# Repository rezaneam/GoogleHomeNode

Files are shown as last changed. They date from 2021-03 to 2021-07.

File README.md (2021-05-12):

# Smart IoT Sensor - Lite Version of [sAmbiente](https://github.com/rezaneam/sAmbiente)

This project introduces proof of concept for a Smart Home Device/Sensor/Monitoring with a different approach.
In this project, Bosch & TI environment sensors (BMP280, BME280, BME680, HDC1080) were utilized to monitor the temperature, humidity, pressure, and air quality.

<p align="center">
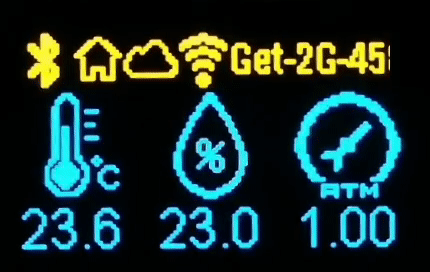
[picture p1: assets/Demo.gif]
  
</p>

## What is innovative in this project

- The configuration process of the Smart IoT Sensor is straightforward and you can update it at anytime.
- The Sensor pushes real-time readings via BluetoothLE to multiple connected devices.
- Against many available solutions, you don't need to open a port in your router/modem/firewall. That's really cumbersome and may be secuirty issues.
- You don't need to deal with DNS and static IP address. that's a real pain.
- You don't need to register on expensive and complicated services (Azure IoT Hub service has a free plan).
- You can customize the whole project with a little effort.

## Components

This project includes the following components

- ESP32 (Smart IoT Sensor):

It's the main IoT device which basically is an ESP32 module connected to an environment sensor. The module needs to connect to the Internet via WiFi and connect to Azure services. This project is written in `Platform IO` so it should take care of everything (external libraries) if you use `Platform IO`.
You should be able to connect to the device and configure it via BluetoothLE and at any time, you can update the sensor configuration without any need to reset it.
WiFi name, Password, Azure Connection string, Google Home, device location (for example, kitchen, living room) are configuration values needed to be set. Hopefully, UWP and Xamarin applications will help you to do it with any challenges.

- UWP Application:

This application is just for configuring the Google Home node. It's basically a `Windows 10` application and will show up in `Windows store` soon :)
By the way, you can run on Desktop, Windows Mobile, and `Windows IoT Core` (`Raspberry Pi`).

- ~~Xamarin Application~~: (not ready yet)

This project is an extended version of UWP Application for `Android` and `iOS` platform. Not ready yet.

- Azure:

This is an Azure Function app if you want to use your own `Azure service`. contact me if you can't follow me.

## How set it up

- Google Home Node

First thing first, You need to build the Google Home Node device and program it.
I would recommend you first test it with a very basic ESP32 evaluation board and a BMP280/BME280 breakout board. This setup would cost you less than 5 USD. Of course, having a `SSD1306` is a plus.
Wire the sensor as is shown in the following figure and flash the board via Platform IO in `Visual Studio Code`.

<p align="center">
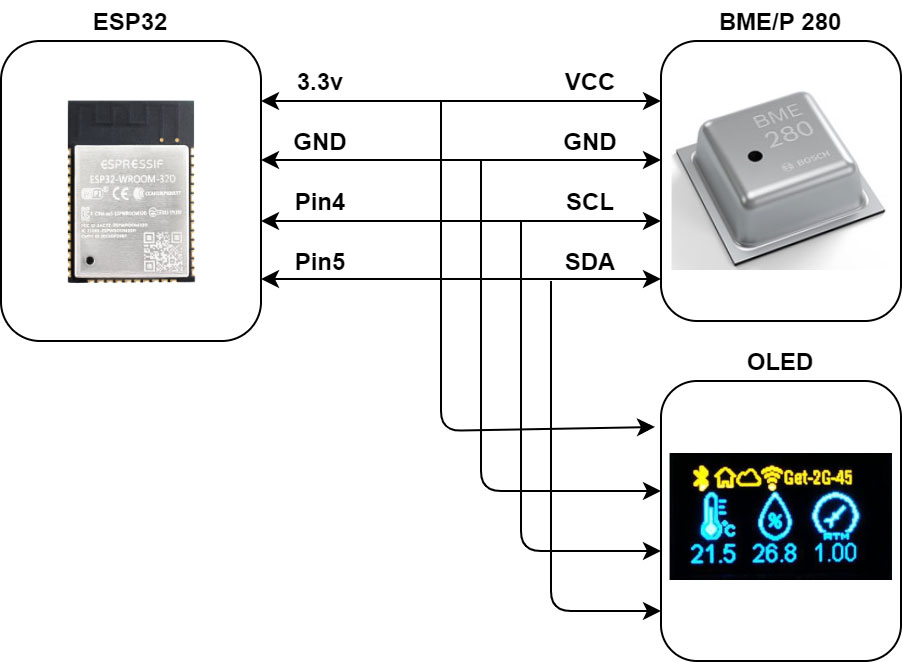
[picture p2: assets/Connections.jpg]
  
</p>

You can always reconfigure the connection by changing the pin numbers in [config.h](ESP32/src/config.h).

You can also use the PCB design to make your custom compact module with more functionality and battery support.
Find the attached 3.5x3.5 cm [PCB design](/KiCad-Design/KiCad-Design.kicad_pcb).

PCB layout

<span align="center">
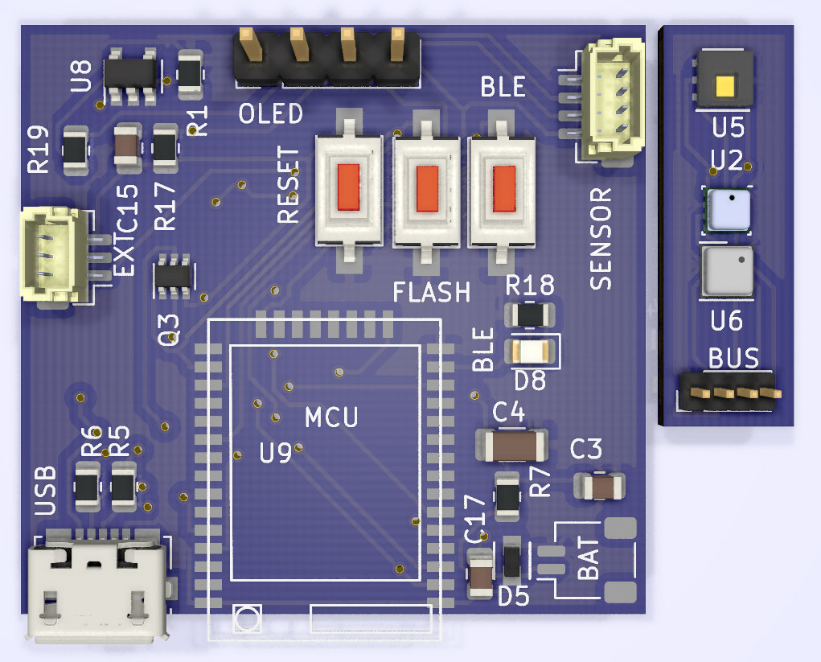
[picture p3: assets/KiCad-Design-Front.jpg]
  
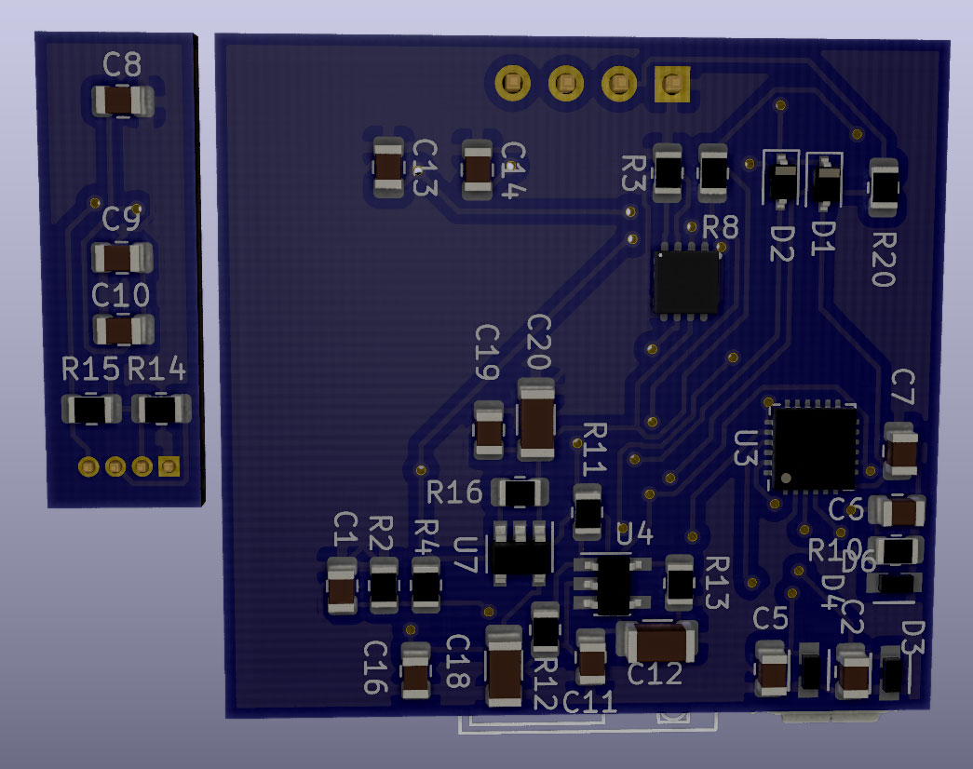
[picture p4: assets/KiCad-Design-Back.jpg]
  
</span>

- Azure IoT Hub

After creating the `Azure` account the first step is to make a new `IoT Hub` service in your Azure account. To do so just type in IoT Hub and create a new account (you pick F1 which is entirely free). Then Navigate to the IoT Hub service you created and make an IoT Device.
Click on the IoT Device that you have just created and copy the connection string. You need to set this connection string in your Google Home node.
To test if this part is working properly just send a direct method with the following payload and check the logs in your serial port.

{
"Action": "Google Home",
"UserID": "`YourUserID`",
"Language": "en",
"Key": "temperature"
}

So, now you are done with this part.

- Azure Function

In the same way make an `Azure Function App` service in your Azure account. Pick .Net 3.1 version and Free version in the Function App.
Open Azure project repository and update the _IoTHubName_, _IoTDeviceName_, and _IoTSharedAccessKey_ values and then Publish the function in your Azure account.
To test this step just copy the Function App **URL** and use postman to send a post message with the following body.

{
"Action": "Google Home",
"UserID": "`YourUserID`",
"Language": "en",
"Key": "temperature"
}

- IFTTT

You need to make an IFTTT account (it's free) and make a scenario called.
Try to create an applet in IFTTT, add `Google Assistant` as a trigger source. Remember to pick _say a phrase with a text ingredient_
Type in your preferred keywords followed by $ sign and provide a response for that.
Then pick `Webhooks` (web request) as the service. So copy and paste the `Azure Function App` URL from the previous step in URL field. You pick either Get or Post request and for the content type choose JSON. paste the following structure there.

{
"Action": "Google Home",
"Language": "en",
"UserID": "`YourUserID`",
"Key": "TextField"
}

## How it is working

The following figure shows the overal concept of the project.

<p align="center">
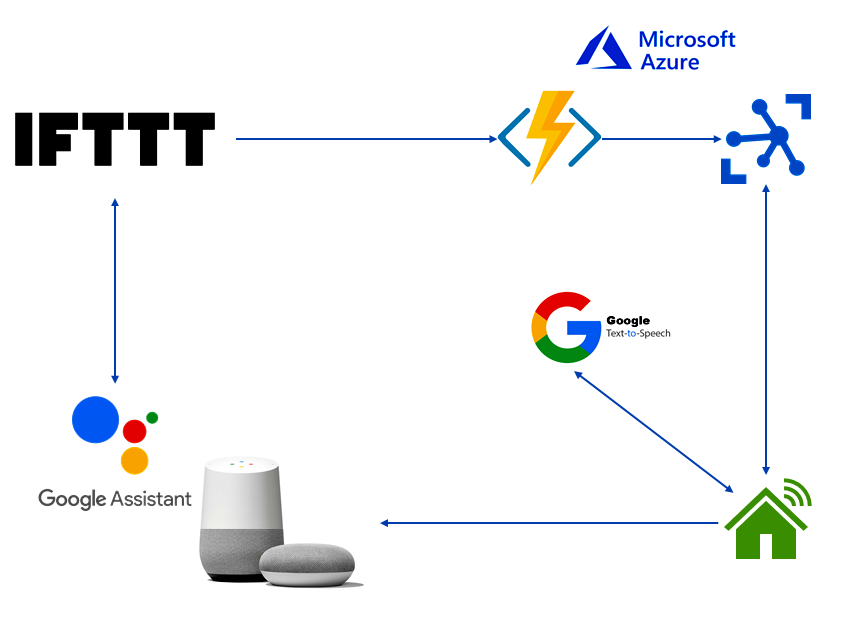
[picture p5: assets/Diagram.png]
  
</p>

The Google Home Node (main ESP32 module) starts to connect to Azure IoT service (as set in the configuration) and tries to find the local `Google Home speaker` (namely Google Home, Google Home Mini, or any Google Home enable speaker). It also drives the OLED and the sensor.
The Google Home Node is always in listening mode (at least for now) and doesn't send any information to `Azure IoT Hub`.

When you ask `Google Assistant` to give you the home temperature (or specific location/node), Google Assistant (not Google Home speaker) triggers an action in the IFTTT (which you have previously defined).

`IFTTT` triggers a webhook (better to an HTTP request) which actually an Azure Function with some inputs (username, keywords).
The received information from Azure Function is sent to the Azure IoT and eventually received by the Google Home Node.

Google Home Node would take action if the received information matches (username, location, etc.). So Google Home Node asks the Google Home speaker (already linked) to say the temperature, humidity, ... values.
I used [esp8266 Google TTS](https://github.com/horihiro/esp8266-google-tts) to generate an audio file and [esp8266 Google Home Notifier](https://github.com/horihiro/esp8266-google-home-notifier) to push the message/notification to the Google Home Speaker.

## Platform/IDE(s)

- [Platform IO](https://platformio.org/)
- [Arduino](https://www.arduino.cc/)
- [Espressif ESP-32](https://www.espressif.com/en/products/socs/esp32)

## Supported Sensors

- [Bosch BMP280](https://www.bosch-sensortec.com/products/environmental-sensors/pressure-sensors/bmp280/)
- [Bosch BME280](https://www.bosch-sensortec.com/products/environmental-sensors/humidity-sensors-bme280/)
- [Bosch BME680](https://www.bosch-sensortec.com/products/environmental-sensors/gas-sensors/bme680/). You need a [permission](https://www.bosch-sensortec.com/media/boschsensortec/downloads/bsec/2017-07-17_clickthrough_license_terms_environmentalib_sw_clean.pdf) to use [Bosch Sensortec Environmental Cluster(BSEC) Library](https://github.com/BoschSensortec/BSEC-Arduino-library). Please visit this [page](https://www.bosch-sensortec.com/software-tools/software/bsec/)
- [Texas Instrument HDC1080](https://www.ti.com/lit/ds/symlink/hdc1080.pdf)

## Dependent Libraries

- [Azure IoT Arduino](https://github.com/Azure/azure-iot-arduino)
- [Azure IoT Protocol HTTP](https://github.com/Azure/azure-iot-arduino-protocol-http)
- [Azure IoT Protocol MQTT](https://github.com/Azure/azure-iot-arduino-protocol-mqtt)
- [Azure IoT Utility](https://github.com/Azure/azure-iot-arduino-utility)
- [NimBLE Arduino](https://github.com/h2zero/NimBLE-Arduino) - Lite version of the BluetoothLE to save some RAM
- [esp8266 Google Home Notifier](https://github.com/horihiro/esp8266-google-home-notifier) - Customized version to support different languages.
- [esp8266 Google TTS](https://github.com/horihiro/esp8266-google-tts)
- [Adafruit BME280 Library](https://github.com/adafruit/Adafruit_BME280_Library) - Locally/Modified in the project
- [ThingPulse SSD1306](https://github.com/ThingPulse/esp8266-oled-ssd1306) - Extensively modified and locally imported.
- [BSEC Arduino Library](https://github.com/BoschSensortec/BSEC-Arduino-library) - Please visit this [page](https://www.bosch-sensortec.com/software-tools/software/bsec/)
- TO DO: [Texas Instrument HDC1080](https://www.ti.com/lit/ds/symlink/hdc1080.pdf)

## Future Improvment

- Improving the UWP Application layout and code logic
- Deploy UWP App in the Windows Store
- Support for Android & iOS platforms (Xamarin Forms)
- Better desgin for multi-language support (EN, DE, FR)
- Find a way to integrate with Google Assistant
- Connect to [HASS](https://www.home-assistant.io/)

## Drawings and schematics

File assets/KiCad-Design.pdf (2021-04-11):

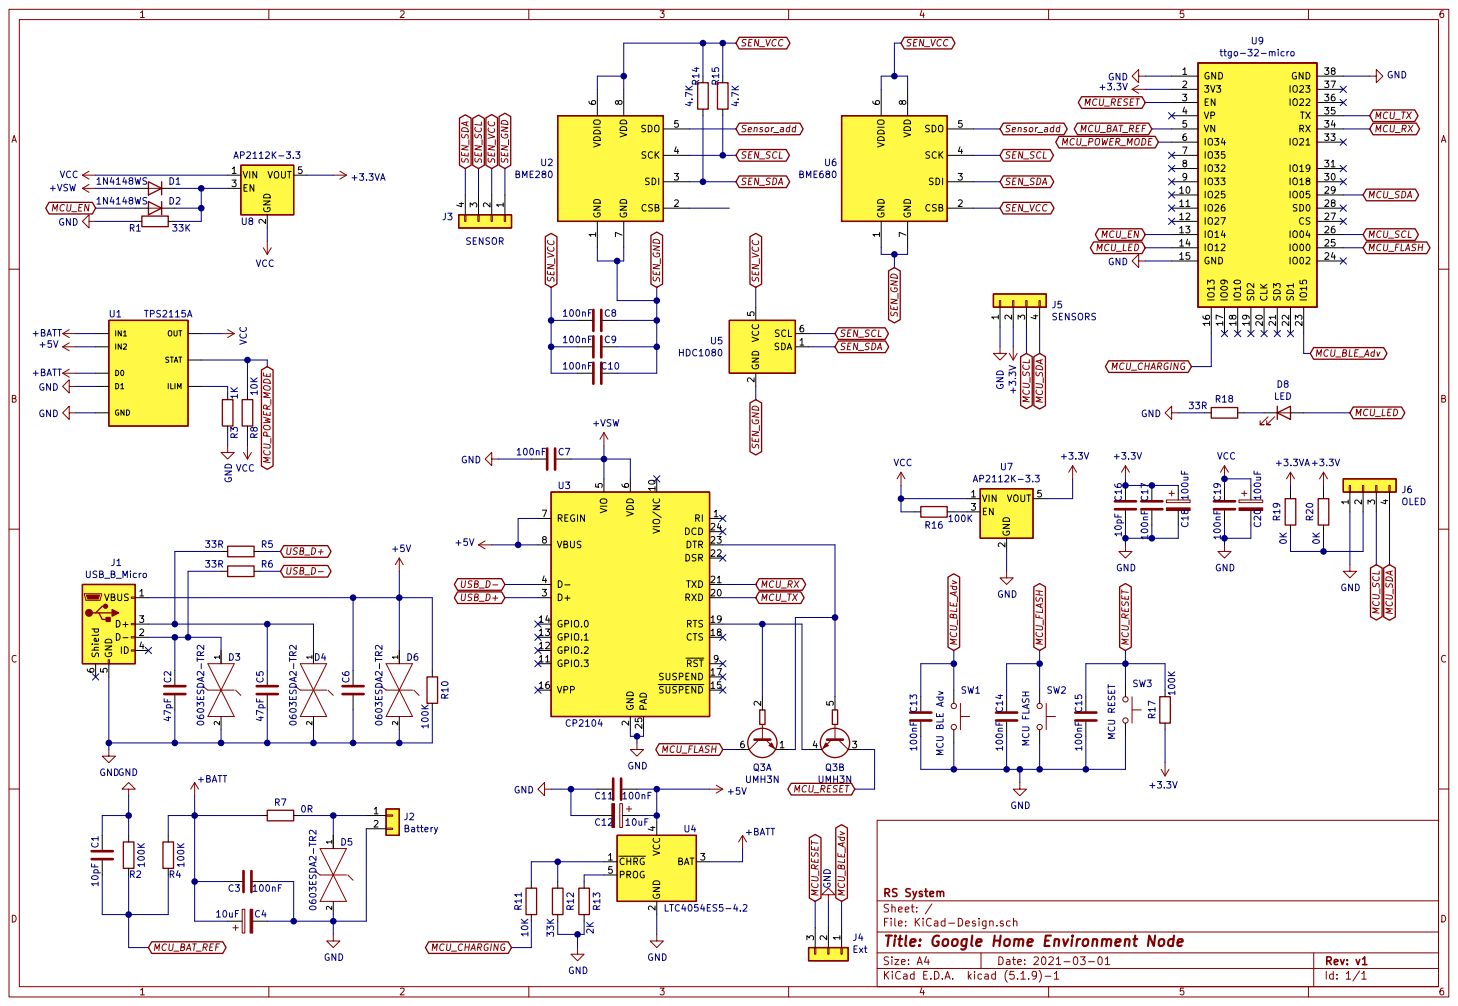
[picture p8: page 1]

1 CSB 2 SDI 3 SCK 4 SDO 5 VDDIO

6 REGIN 7 VBUS 8 RST 9 U3CP2104 GND

2 RXD 20 TXD 21 DSR 22 DTR 23 DCD 24 PAD 25 D+ 3 D- 4 VIO

Id: 1/1 Title: Google Home Environment Node

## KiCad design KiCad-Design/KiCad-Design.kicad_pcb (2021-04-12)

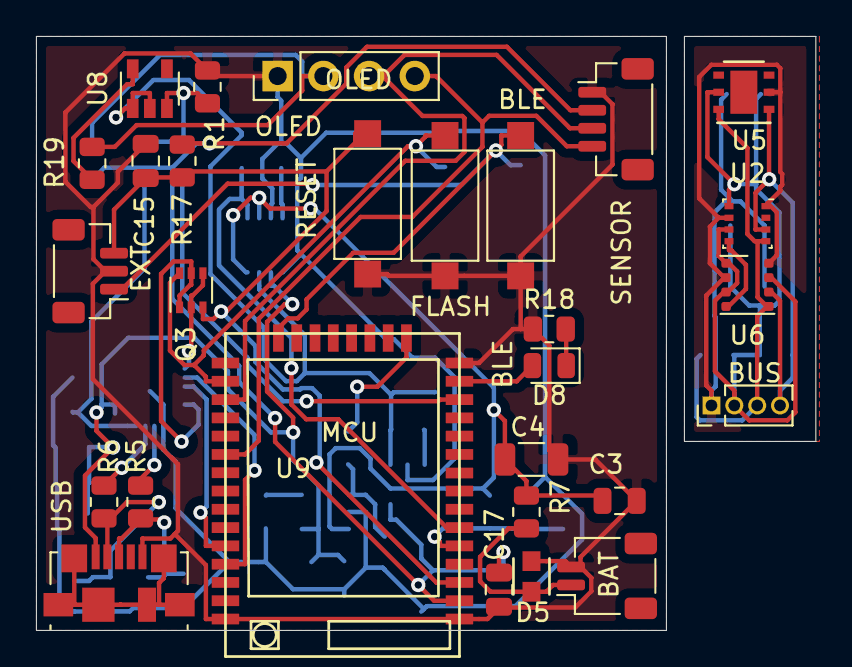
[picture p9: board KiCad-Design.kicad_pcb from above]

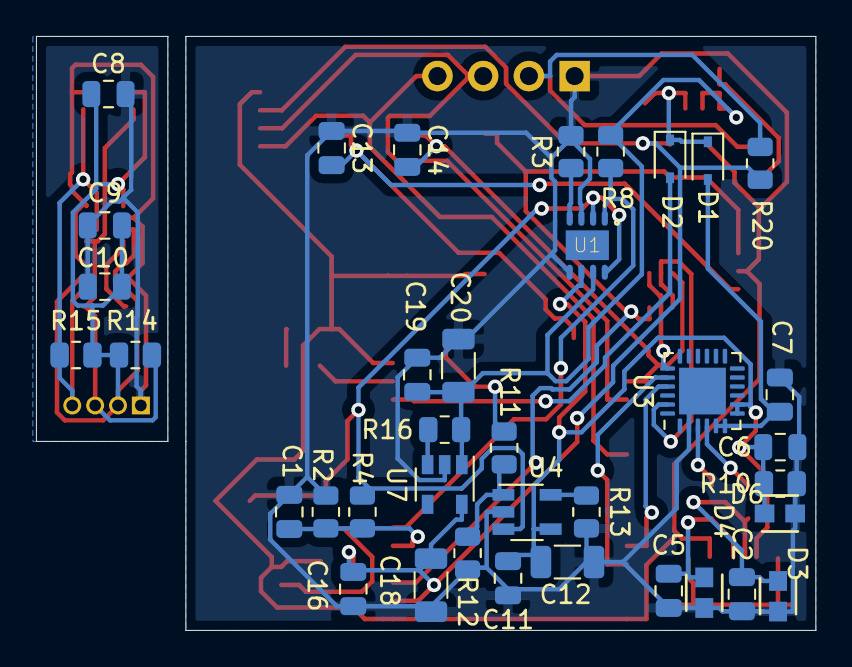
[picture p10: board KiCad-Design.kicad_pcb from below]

Board: 2 copper layers, 43.3 x 33.0 mm, 65 parts (37 on the bottom side), 38 nets.

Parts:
BAT: Battery; JST_SH_SM02B-SRSS-TB_1x02-1MP_P1.00mm_Horizontal
BLE: MCU BLE Adv; SW_SPST_CK_RS282G05A3
BUS: SENSOR; PinHeader_1x04_P1.27mm_Vertical
C1, C16: 10pF; C_0805_2012Metric
C2, C5: 47pF; C_0805_2012Metric
C3, C7, C8, C9, C10, C11, C13, C14, C15, C17, C19: 100nF; C_0805_2012Metric
C4, C12: 10uF; C_1206_3216Metric
C6: 100pF; C_0805_2012Metric
C18, C20: 100uF; C_1206_3216Metric
D1, D2: 1N4148WS; D_SOD-323
D3, D4, D5, D6: 0603ESDA2-TR2; Eaton-0603ESDA-0-0-0
D8: LED; LED_0805_2012Metric
EXT: Ext; JST_SH_BM03B-SRSS-TB_1x03-1MP_P1.00mm_Vertical
FLASH: MCU FLASH; SW_SPST_CK_RS282G05A3
J1: USB_B_Micro; USB_Micro-B_Molex_47346-0001
OLED: OLED; PinHeader_1x04_P2.54mm_Vertical
Q3: UMH3N; SOT-363_SC-70-6
R1, R12: 33K; R_0805_2012Metric
R2, R4, R10, R16, R17: 100K; R_0805_2012Metric
R3: 1K; R_0805_2012Metric
R5, R6, R18: 33R; R_0805_2012Metric
R7: 0R; R_0805_2012Metric
R8, R11: 10K; R_0805_2012Metric
R13: 2K; R_0805_2012Metric
R14, R15: 4.7K; R_0805_2012Metric
R19, R20: 0K; R_0805_2012Metric
RESET: MCU RESET; SW_SPST_CK_RS282G05A3
SENSOR: SENSORS; JST_SH_BM04B-SRSS-TB_1x04-1MP_P1.00mm_Vertical
U1: TPS2115A; SON-8
U2: BME280; Bosch_LGA-8_2.5x2.5mm_P0.65mm_ClockwisePinNumbering
U3: CP2104; QFN-24-1EP_4x4mm_P0.5mm_EP2.6x2.6mm
U4: LTC4054ES5-4.2; TSOT-23-5
U5: HDC1080; Texas_PWSON-N6
U6: BME680; Bosch_LGA-8_3x3mm_P0.8mm_ClockwisePinNumbering
U7, U8: AP2112K-3.3; SOT-23-5
U9: ttgo-32-micro; TTGO-32-MICRO

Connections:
+3.3VA: R19.2, U8.5
+3V3: C16.2, C17.2, C18.1, R17.2, R20.2, SENSOR.2, U7.5, U9.2
+5V: C6.2, C11.1, C12.1, D6.1, J1.1, R10.2, U1.6, U3.7, U3.8, U4.4
+BATT: C3.2, C4.1, R4.2, R7.2, U1.2, U1.8, U4.3
+VSW: C7.2, D1.2, U3.5, U3.6
GND: BAT.2, BLE.2, C1.2, C2.1, C3.1, C4.2, C5.1, C6.1, C7.1, C11.2, C12.2, C13.1, C14.1, C15.1, C16.1, C17.1, C18.2, C19.1, C20.2, D3.2, D4.2, D5.2, D6.2, EXT.2, FLASH.2, J1.5, OLED.1, R1.2, R2.2, R3.2, R10.1, R12.1, R13.1, R18.1, RESET.2, SENSOR.1, U1.3, U1.5, U3.2, U3.25, U4.2, U7.2, U9.1, U9.15, U9.38
MCU_BAT_REF: C1.1, R2.1, R4.1, U9.5
MCU_BLE_Adv: BLE.1, C13.2, EXT.1, U9.23
MCU_CHARGING: R11.2, U9.16
MCU_EN: D2.2, U9.13
MCU_FLASH: C14.2, FLASH.1, Q3.6, U9.25
MCU_LED: D8.2, U9.14
MCU_POWER_MODE: R8.1, U1.1, U9.6
MCU_RESET: C15.2, EXT.3, Q3.3, R17.1, RESET.1, U9.3
MCU_RX: U3.21, U9.34
MCU_SCL: OLED.3, SENSOR.3, U9.26
MCU_SDA: OLED.4, SENSOR.4, U9.29
MCU_TX: U3.20, U9.35
unnamed: C2.2, D3.1, J1.2, R6.1
unnamed: C5.2, D4.1, J1.3, R5.1
unnamed: D1.1, D2.1, R1.1, U8.3
unnamed: BAT.1, D5.1, R7.1
unnamed: D8.1, R18.2
unnamed: OLED.2, R19.1, R20.1
unnamed: Q3.1, Q3.5, U3.23
unnamed: Q3.2, Q3.4, U3.19
unnamed: R3.1, U1.4
unnamed: R11.1, R12.2, U4.1
unnamed: R13.2, U4.5
unnamed: R16.1, U7.3
SEN_GND: BUS.1, C8.2, C9.2, C10.2, U2.1, U2.7, U5.2, U6.1, U6.7
SEN_SCL: BUS.3, R15.1, U2.4, U5.6, U6.4
SEN_SDA: BUS.4, R14.1, U2.3, U5.1, U6.3
SEN_VCC: BUS.2, C8.1, C9.1, C10.1, R14.2, R15.2, U2.6, U2.8, U5.5, U6.2, U6.6, U6.8
Sensor_add: U2.5, U6.5
USB_D+: R5.2, U3.3
USB_D-: R6.2, U3.4
VCC: C19.2, C20.1, R8.2, R16.2, U1.7, U7.1, U8.1, U8.2

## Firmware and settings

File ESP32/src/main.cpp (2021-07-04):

#include <main.h>

// TODO: Converting the Bluetooth Stack value to digits
// TODO: Showing the last status save
// TODO: Auto Detect different sensor address
// TODO: Adding Support for handling wider Azure commands
// TODO: Azure IoT Memory leak issue after de_init
// TODO: Improving the memory consumption & remove memory leaks
// TODO: Support for internet conenction
// TODO: Support for continues WiFi connectivity & pinging the gateway
// TODO: Investigate the break-down when Sensor failing
// TODO: Adding support for HDC1080

void setup()
{
  // put your setup code here, to run once:
  Serial.begin(SERIAL_BAUDRATE);
  if (VERBOSE)
    printf("ESP-IDF version is : %s\r\n", esp_get_idf_version());

  eventQueue.reserve(3);

  EEPROM.begin(EEPROM_SIZE);
  ReadFlash();

  Oled.Initialize(true);

  if (OLED_SCL_PIN != SENSOR_SCL_PIN || OLED_SDA_PIN != SENSOR_SDA_PIN)
  {
    Wire1.begin(SENSOR_SDA_PIN, SENSOR_SCL_PIN, SDA_Frequency);
    Sensor.Initialize(Wire1, VERBOSE);
  }
  else
    Sensor.Initialize(Wire, VERBOSE);

  initializeTimer();

  BluetoothLE.Initialize(BLE_DEVICE_NAME, &EnqueueEvent, VERBOSE);
  BluetoothLE.Setup();
  pinMode(BLE_ADVERTISE_LED_PIN, OUTPUT);
  digitalWrite(BLE_ADVERTISE_LED_PIN, LOW);
  pinMode(BLE_ADVERTISE_ENABLE_PIN, INPUT_PULLUP); // External PIN for triggering the advertise for BLE
  attachInterrupt(digitalPinToInterrupt(BLE_ADVERTISE_ENABLE_PIN), handleExternalInterrupt, FALLING);

  wireless.Initialize(&EnqueueEvent, "GH-Home", (char *)VERBOSE);

  googleHome.Initialize(&EnqueueEvent, VERBOSE);

  if (HasValidWiFi())
    EnqueueEvent(CustomEvents::EVENT_WIFI_TRY_CONNECT);

  if (Sensor.CheckStatus())
    if (!Sensor.LoadState() & VERBOSE)
      printf("Failed to load the BSEC state\r\n");

  switch (Sensor.sensorType)
  {
  case SensorType::BMP280_Sensor:
    Oled.ShowMessage("BMP280", "Sensor", "TEMP + BAR");
    break;

  case SensorType::BME280_Sensor:
    Oled.ShowMessage("BME280", "Sensor", "TEMP + BAR + HUM");
    break;

  case SensorType::BME680_Sensor:
    Oled.ShowMessage("BME680", "Sensor", "TEMP + BAR + HUM + AQI");
    break;

  case SensorType::No_Sensor:
    Oled.ShowMessage("Error", "No Sensor found", "Check the connections");
    break;
  }
}

void loop()
{
  if (fireIoT)
  {
    if (connectionStatus.isInternetConnected)
      azureIoT.HeartBeat();
    fireIoT = false;
  }

  if (tryStartBLE)
  {
    tryStartBLE = false;
    if (!connectionStatus.isBLEAdvertising)
      EnqueueEvent(CustomEvents::EVENT_BLE_TRY_START_ADV);
  }

  if (ble_advertize_timeOut == 0)
    EnqueueEvent(CustomEvents::EVENT_BLE_TRY_STOP_ADV);

  switch (DequeueEvent())
  {
  case CustomEvents::EVENT_BLE_CONNECTED:
    connectionStatus.isBLEConnected = true;
    UpdateStatus(false, true);
    break;
  case CustomEvents::EVENT_BLE_DISCONNECT:
    connectionStatus.isBLEConnected = false;
    ble_advertize_timeOut = BLE_ADVERTISE_TIMEOUT_MS;
    UpdateStatus(false, true);
    break;
  case CustomEvents::EVENT_BLE_TRY_STOP_ADV:
    BluetoothLE.StopAdvertise();
    digitalWrite(BLE_ADVERTISE_LED_PIN, LOW);
    connectionStatus.isBLEAdvertising = false;
    ble_advertize_timeOut = BLE_ADVERTISE_TIMEOUT_MS;
    UpdateStatus(false, true);
    break;
  case CustomEvents::EVENT_BLE_TRY_START_ADV:
    BluetoothLE.StartAdvertise();
    connectionStatus.isBLEAdvertising = true;
    ble_advertize_timeOut = BLE_ADVERTISE_TIMEOUT_MS;
    UpdateStatus(false, true);
    break;
  case CustomEvents::EVENT_WIFI_START_SCAN:
    wireless.ScanNodes();
    break;
  case CustomEvents::EVENT_WIFI_SCAN_COMPLETED:
    BluetoothLE.SetSSIDs(wireless.SSIDs);
    break;
  case CustomEvents::EVENT_WIFI_TRY_CONNECT:
    wireless.TryConnect(GetFlashValue(EEPROM_VALUE::WiFi_SSID), GetFlashValue(EEPROM_VALUE::WiFi_Password));
    break;
  case CustomEvents::EVENT_WIFI_FORCE_CONNECT:
    wireless.TryConnect(GetFlashValue(EEPROM_VALUE::WiFi_SSID), GetFlashValue(EEPROM_VALUE::WiFi_Password), true);
    break;
  case CustomEvents::EVENT_WIFI_TRY_DISCONNECT:
    wireless.Disconnect();
    EnqueueEvent(CustomEvents::EVENT_WIFI_DISCONNECTED);
    EnqueueEvent(CustomEvents::EVENT_AZURE_IOT_HUB_TRY_DISCONNECT);
    break;
  case CustomEvents::EVENT_WIFI_CONNECTED:
    connectionStatus.isWiFiConnected = true;
    BluetoothLE.SetSSID(GetFlashValue(EEPROM_VALUE::WiFi_SSID));
    ssid = GetFlashValue(EEPROM_VALUE::WiFi_SSID);
    UpdateStatus(true, true);
    ConfigureTime();
    EnqueueEvent(CustomEvents::EVENT_AZURE_IOT_HUB_TRY_CONNECT);
    EnqueueEvent(CustomEvents::EVENT_GOOGLE_HOME_TRY_CONNECT);
    break;
  case CustomEvents::EVENT_WIFI_DISCONNECTED:
    connectionStatus.isWiFiConnected = false;
    ssid = "";
    UpdateStatus(true, true);
    break;
  case CustomEvents::EVENT_WIFI_PASS_RECEIVED:
    BluetoothLE.StoreWiFiAuthentication();
    break;
  case CustomEvents::EVENT_WIFI_AZURE_KEY_RECEIVED:
    BluetoothLE.StoreAzureAuthentication();
    EnqueueEvent(CustomEvents::EVENT_AZURE_IOT_HUB_TRY_CONNECT);
    break;
  case CustomEvents::EVENT_GOOGLE_HOME_TRY_CONNECT:
    if (connectionStatus.isWiFiConnected && HasValidHome())
      googleHome.TryConnect(GetFlashValue(EEPROM_VALUE::Google_Home_Name));
    break;
  case CustomEvents::EVENT_GOOGLE_HOME_CONNECTED:
    connectionStatus.isHomeConnected = true;
    BluetoothLE.SetGoogleHomeName(GetFlashValue(EEPROM_VALUE::Google_Home_Name));
    UpdateStatus(true, true);
    break;
  case CustomEvents::EVENT_GOOGLE_REPORT_TEMPERATURE:
    UpdateStatus(false, true, true);
    if (connectionStatus.isHomeConnected)
      googleHome.NotifyTemperature((int)Sensor.Measurments.cur_temperature, azureIoT.GetLanguage());
    UpdateStatus(false, true);
    break;

  case CustomEvents::EVENT_GOOGLE_PHRASE:
    //printf("Phrase message received: %d\r\b", azureIoT.phrase);
    break;

  case CustomEvents::EVENT_GOOGLE_REPORT_TEMPERATURE_SUMMARY:
    UpdateStatus(false, true, true);
    if (connectionStatus.isHomeConnected)
      googleHome.NotifyTemperatureSummary(
          (int)Sensor.Measurments.ave_temperature,
          (int)Sensor.Measurments.min_temperature,
          (int)Sensor.Measurments.max_temperature,
          azureIoT.GetLanguage());
    UpdateStatus(false, true);
    break;
  case CustomEvents::EVENT_GOOGLE_REPORT_HUMIDITY:
    UpdateStatus(false, true, true);
    if (connectionStatus.isHomeConnected)
      googleHome.NotifyHumidity((int)Sensor.Measurments.cur_humidity, azureIoT.GetLanguage());
    UpdateStatus(false, true);
    break;
  case CustomEvents::EVENT_GOOGLE_REPORT_HUMIDITY_SUMMARY:
    UpdateStatus(false, true, true);
    if (connectionStatus.isHomeConnected)
      googleHome.NotifyHumiditySummary(
          (int)Sensor.Measurments.ave_humidity,
          (int)Sensor.Measurments.min_humidity,
          (int)Sensor.Measurments.max_humidity,
          azureIoT.GetLanguage());
    UpdateStatus(false, true);
    break;
    break;
  case CustomEvents::EVENT_AZURE_IOT_HUB_TRY_CONNECT:
    if (!HasValidAzure() | !connectionStatus.isWiFiConnected)
      break;
    struct tm timeinfo;
    if (getLocalTime(&timeinfo))
    {
      bool result = azureIoT.Initialize(
          (GetFlashValue(EEPROM_VALUE::Azure_IoT_Hub)).c_str(),
          &EnqueueEvent, &NotifyPhrase,
          (GetFlashValue(EEPROM_VALUE::User_Name)).c_str(),
          (GetFlashValue(EEPROM_VALUE::Device_Location)).c_str(),
          VERBOSE);
      EnqueueEvent(result ? CustomEvents::EVENT_AZURE_IOT_HUB_CONNECTED : CustomEvents::EVENT_AZURE_IOT_HUB_DISCONNECTED);
    }
    break;
  case CustomEvents::EVENT_AZURE_IOT_HUB_CONNECTED:
    connectionStatus.isCloudConnected = true;
    UpdateStatus(true, true);
    break;
  case CustomEvents::EVENT_AZURE_IOT_HUB_TRY_DISCONNECT:
    azureIoT.Distroy();
    EnqueueEvent(CustomEvents::EVENT_AZURE_IOT_HUB_DISCONNECTED);
    break;
  case CustomEvents::EVENT_AZURE_IOT_HUB_DISCONNECTED:
    connectionStatus.isCloudConnected = false;
    UpdateStatus(true, true);
    break;
  case CustomEvents::EVENT_FACTORY_RESET:
    Oled.ShowMessage("Factory Reset", "Ereasing...");
    if (VERBOSE)
      printf("Factory Reset triggered by user\r\n");
    EraseFlash();
    delay(5000);
    ESP.restart();
    break;
  case CustomEvents::EVENT_FACTORY_RESET_SAFE:
    Oled.ShowMessage("Factory Reset", "Safe earsing...");
    if (VERBOSE)
      printf("Factory Reset [Safe] triggered by user\r\n");
    EraseFlash(true);
    delay(5000);
    ESP.restart();
    break;
  case CustomEvents::EVENT_RESTART:
    Oled.ShowMessage("Restarting...", "Please wait.");
    if (VERBOSE)
      printf("Rebooting triggered by user\r\n");
    delay(5000);
    ESP.restart();
    break;
  case CustomEvents::EVENT_LOW_RAM_RESTART:
    Oled.ShowMessage("Restarting...", "Low Memory!");
    if (VERBOSE)
      printf("Rebooting due to low memeory\r\n");
    delay(5000);
    ESP.restart();
    break;
  default:
    break;
  }
  if (readSenor)
  {
    float freeHeap = 100.0 * ESP.getFreeHeap() / ESP.getHeapSize();
    char buffer[100] = "";
    connectionStatus.isWiFiConnected = wireless.IsConnected();
    if (connectionStatus.isWiFiConnected)
    {
      connectionStatus.isInternetConnected = wireless.IsOnline();
      connectionStatus.isCloudConnected = connectionStatus.isInternetConnected;
      if (connectionStatus.isInternetConnected)
      {
        getTimeString(&buffer[0]);
      }
    }
    else
    {
      connectionStatus.isInternetConnected = false;
      connectionStatus.isHomeConnected = false;
      if (HasValidWiFi())
        EnqueueEvent(CustomEvents::EVENT_WIFI_TRY_CONNECT);
    }

    UpdateStatus(true, true);
    if (Sensor.CheckStatus())
    {

      if (Sensor.UpdateMeasurments())
      {
        float temperature = Sensor.Measurments.cur_temperature;
        float humidity = Sensor.Measurments.cur_humidity;
        float pressure = Sensor.Measurments.cur_pressure;
        float airQuality = Sensor.Measurments.cur_airQuality;
        if (VERBOSE)
        {

          printf(">> Free Heap %2.2f%% %s [%d]", freeHeap, buffer, Sensor.Measurments.total_readgings);
          printf(" Temperature: %2.1fc(%2.1f-%2.1f)[%2.1f]",
                 temperature, Sensor.Measurments.min_temperature, Sensor.Measurments.max_temperature, Sensor.Measurments.ave_temperature);
          printf(" Pressure: %2.2fatm(%2.2f-%2.2f)[%2.2f]",
                 pressure / 101325, Sensor.Measurments.min_pressure / 101325, Sensor.Measurments.max_pressure / 101325, Sensor.Measurments.ave_pressure / 101325);
          if (humidity >= 0)
            printf(" Humidity: %2.1f%%(%2.1f-%2.1f)[%2.1f] ",
                   humidity, Sensor.Measurments.min_humidity, Sensor.Measurments.max_humidity, Sensor.Measurments.ave_humidity);
          if (airQuality >= 0)
          {
            printf("AirQuality: %2.1f(%2.1f-%2.1f)[%2.1f]",
                   airQuality, Sensor.Measurments.min_air_quality, Sensor.Measurments.max_air_quality, Sensor.Measurments.ave_airQuality);
            printf(" VOC: %2.1f%% CO2: %2.1f",
                   Sensor.Measurments.VOC, Sensor.Measurments.CO2);
            if (airQuality > 200 & !isHighAQI)
            {
              NotifyPhrase("Warning. Very poor air quality detected.", Languages::English);
              isHighAQI = true;
            }
            else
              isHighAQI = false;
          }
          printf("\r\n");
        }
        BluetoothLE.UpdateSensorValues(temperature, humidity, pressure, airQuality);
      }
    }
    else
    {
      if (VERBOSE)
        printf(">> Free Heap %2.2f%% %s\r\n", buffer, freeHeap);
    }
    readSenor = false;

    if (freeHeap <= MinimumAllowHeapSize)
      EnqueueEvent(CustomEvents::EVENT_LOW_RAM_RESTART);
  }
  if (secondFlag)
  {
    RefreshOLED();
    Sensor.Run();
    storeBSECstateCountdown--;
    if (storeBSECstateCountdown == 0)
      storeBSECstateCountdown = Sensor.StoreState() ? UPDATE_BSEC_STATE_INTERVAL_SEC : RETRY_UPDATE_BSEC_STATE_INTERVAL_SEC;

    secondFlag = false;
  }
}

void getTimeString(char *buffer)
{
  time_t now;
  time(&now);
  tm *ltm = localtime(&now);

  sprintf(buffer, "%d/%d/%d %d:%d:%d",
          ltm->tm_mday, ltm->tm_mon + 1, ltm->tm_year + 1900, ltm->tm_hour, ltm->tm_min, ltm->tm_sec);

  if (ltm->tm_min == START_OF_DAY_MIN & ltm->tm_hour == START_OF_DAY_HOUR)
    Sensor.ResetReport();
}

void NotifyPhrase(std::string phrase, Languages language)
{
  googleHome.NofityPhrase(phrase, language);
}

void EnqueueEvent(const CustomEvents &newEvent)
{
  if (std::find(eventQueue.begin(), eventQueue.end(), newEvent) == eventQueue.end())
    eventQueue.emplace_back(newEvent);
}

CustomEvents DequeueEvent()
{
  if (eventQueue.size() == 0)
    return CustomEvents::EVENT_NONE;
  CustomEvents returnEvent = eventQueue.front();
  eventQueue.erase(eventQueue.begin());
  return returnEvent;
}

void ConfigureTime()
{
  HTTPClient http;
  const char *ntpServer = "pool.ntp.org";
  const char *timeApiUrl = "http://worldtimeapi.org/api/ip";

  http.begin(timeApiUrl);
  int httpCode = http.GET();

  if (httpCode != 200)
  {
    printf("Unable to fetch the time info\r\n");
    configTime(0, 0, ntpServer);
    return;
  }
  String response = http.getString();
  long offset = response.substring(response.indexOf("\"raw_offset\":") + 13, response.indexOf(",\"timezone\":")).toFloat();
  long daylight_offset = response.substring(response.indexOf("\"dst_offset\":") + 13, response.indexOf(",\"dst_until\":")).toFloat();
  http.end();

  configTime(offset, daylight_offset, ntpServer);
}

void UpdateStatus(bool BLE, bool OLED, bool isNotifying)
{
  if (OLED)
    Oled.ReferessStatusArea(connectionStatus, ssid, isNotifying);
  if (BLE)
    BluetoothLE.UpdateConnectionStatus(connectionStatus);
}

void RefreshOLED()
{

  changeDisplayTimeout--;
  if (changeDisplayTimeout > 0)
    return;
  if (Sensor.sensorType == SensorType::No_Sensor)
    return;
  bool isBME680 = Sensor.sensorType == SensorType::BME680_Sensor;
  bool isBME280 = Sensor.sensorType == SensorType::BME280_Sensor;
  switch (Oled.CurrentShow)
  {
  case DisplayStatus::AllSensors:
    Oled.ShowMSummary(
        Sensor.Measurments.ave_temperature,
        Sensor.Measurments.min_temperature,
        Sensor.Measurments.max_temperature,
        DisplayStatus::TemperatureSensor);
    changeDisplayTimeout = 2;
    return;
  case DisplayStatus::TemperatureSensor:
    Oled.ShowMSummary(
        Sensor.Measurments.ave_pressure,
        Sensor.Measurments.min_pressure,
        Sensor.Measurments.max_pressure,
        DisplayStatus::PressureSensor);
    changeDisplayTimeout = 2;
    return;
  case DisplayStatus::PressureSensor:
    if (isBME280 | isBME680)
    {
      Oled.ShowMSummary(
          Sensor.Measurments.ave_humidity,
          Sensor.Measurments.min_humidity,
          Sensor.Measurments.max_humidity,
          DisplayStatus::HumiditySensor);
      changeDisplayTimeout = 2;
      return;
    }
    break;
  case DisplayStatus::HumiditySensor:
    if (!isBME680)
      break;
    Oled.ShowMSummary(
        Sensor.Measurments.calibrationStatus >= SensorCalibrationStatus::MEDIUM_ACCURACY ? Sensor.Measurments.ave_airQuality : Sensor.Measurments.gas_resistance,
        Sensor.Measurments.min_air_quality,
        Sensor.Measurments.max_air_quality,
        DisplayStatus::AirQualitySensor,
        Sensor.Measurments.calibrationStatus);
    changeDisplayTimeout = 2;
    return;
    break;

  case DisplayStatus::AirQualitySensor:
    if (Sensor.Measurments.calibrationStatus >= SensorCalibrationStatus::MEDIUM_ACCURACY)
    {
      Oled.ShowAirQualitySummary(Sensor.Measurments.cur_airQuality, Sensor.Measurments.VOC);
      changeDisplayTimeout = 2;
      return;
    }
    break;
  }

  if (Oled.CurrentShow != DisplayStatus::Time && connectionStatus.isWiFiConnected)
  {
    time_t now;
    time(&now);
    tm *ltm = localtime(&now);
    Oled.ShowDateTime(ltm);
    changeDisplayTimeout = 2;
    return;
  }
  Oled.RefressSensorArea(
      Sensor.Measurments.cur_temperature,
      Sensor.Measurments.cur_humidity,
      Sensor.Measurments.cur_pressure,
      Sensor.Measurments.cur_airQuality,
      Sensor.Measurments.calibrationStatus);
  changeDisplayTimeout = 4;
}

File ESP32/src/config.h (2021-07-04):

#pragma once

#define SENSOR_SDA_PIN 21
#define SENSOR_SCL_PIN 22
#define OLED_SDA_PIN 21// 5 // 21
#define OLED_SCL_PIN 22 // 4 // 22
#define SDA_Frequency 400000
#define OLED_Address 0x3c

#define BLE_ADVERTISE_TIMEOUT_S 60  // BLE advertising timeout
#define BLE_ADVERTISE_ENABLE_PIN 25 //02 // 33 // 15
#define BLE_ADVERTISE_LED_PIN 14
#define SENSOR_READ_INTERVAL 60

#define UPDATE_BSEC_STATE_INTERVAL 6         // interval of Update/Store status of BME680 into Flash in hours
#define RETRY_UPDATE_BSEC_STATE_INTERVAL 0.5 // interval of retrying Update/Store status of BME680 into Flash in hours

#define START_OF_DAY_HOUR 06 // Start of each day for daliy report (Hour number)
#define START_OF_DAY_MIN 00  // Start of each day for daliy report (Minute number)

#define EEPROM_SIZE 512
#define SERIAL_BAUDRATE 115200

#define VERBOSE true

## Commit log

2020-12-25 * Adding ESP32 project in platformio * Configuring the project * Adding the basic functionality * Adding basic BLE GATT * Adding basic WiFi
    [default_16MB.csv, default_8MB.csv, huge_app.csv]
2020-12-25 Adding support for external button triggered BLE Adding extension for showing BLE and WiFi status on OLEd
2020-12-28 * Adding BLE descriptors for notifying values * Updating the sensor values in the BLE stack
2021-01-02 * Removing redundant serial prints * Switching to NimBLE library
2021-01-02 * Adding the missing code for monitoring the changes done by the user. (onWrite) * Fixing the notify trigger by checking the characteristics is notifiable
    [main.cpp]
2021-01-03 UWP: Adding basics of the Config Tool - Google Home Node * Adding search and connect to device (deviceWatcher) * Adding google node class (services, characteristics, descriptors) * Adding subscribers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
2021-01-05 * Fixing protocol error issue for wireless password * improving the logic for setting SSID & Password and connecting to WiFi
    [main.cpp]
2021-01-29 Fixing the sensor measurements digits for BME680
2021-01-30 Adding the basic support for handling Azure messages * temperature & humidity
2021-01-30 Adding Support for Device location & Securing the Azure Connection string
2021-01-30 Adding the basic support for setting (1) google home name, (2) azure connections string, (3) device location
2021-02-01 Fixing the missing definition
    [main.cpp]
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2021-02-03 Fixing BLE advertise timeout logic Correct the Azure connection events improving OLED logic improving the event handling the in main.cpp abstracting the frequent update status tasks
    [main.cpp]
2021-02-03 Adding the missing google home status update
    [main.cpp]
2021-02-04 Adding missing stuff after moving BLE to a class
    [main.cpp]
2021-02-05 * Use connection string stored in the flash * Adding verbose flag for printing outputs
2021-02-09 Adding support for device location and username in the Flash
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2021-02-09 Adding characteristics for username and device location in BLE
2021-02-12 Fixing the BLE Characteristics Initialization
    [main.cpp]
2021-02-12 Fixing the bug with userid and device location
2021-02-13 UWP App: Improving the view + support for the device disconnect
2021-02-13 UWP App : Adding the basic support for the sensor values
2021-03-01 PCB Adding PCB Design
    [KiCad-Design.kicad_pcb, KiCad-Design.sch]
2021-03-02 PCB : Small update on the PCB design
    [KiCad-Design.kicad_pcb, KiCad-Design.sch]
2021-03-03 PCB : Initial PCB Design
    [KiCad-Design.kicad_pcb]
2021-03-03 PCB : Adding Missing files
    [KiCad-Design.dsn]
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2021-03-03 PCB : Finalizing the PCB v1
    [KiCad-Design.kicad_pcb]
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2021-03-03 ESP32 : Fixing the buid failure
    [main.cpp]
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2021-03-04 PCB : Adjusting the labels on the PCB file
    [KiCad-Design.kicad_pcb]
2021-03-04 Document : Adding PCB images in the README.md
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2021-03-06 ESP32 : Adding initial support for daily summary of measurements
2021-03-06 ESP32 : changing a dependency to something that allows us to modify the language
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2021-03-07 ESP32 : Fixing min/max measurements
    [main.cpp]
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2021-03-09 ESP32 : Downgrading espressif32 v3.0.0 - due to introduced bug in v3.1.0
2021-03-09 ESP32 : Fixing the font size on the OLED when resting
2021-03-09 ESP32 : Introducing the basic temperature summary report
2021-03-09 ESP32 : Adding support for handling temperature summary
2021-03-09 ESP32 : Fixing sensor values
2021-03-09 ESP32 : Fixing sensor's initial value (for pressure didn't work the last one)
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2021-03-09 ESP32 : Fixing the initial value overflow issue
2021-03-09 ESP32 : adding logic for showing min/max values on OLED
2021-03-09 ESP32 : Adding rotary logic for displaying sensor measurements
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2021-03-10 ESP32 : Fixing Display loop issue when using air quality sensor + checking the wifi connectivity before try to connect to the cloud
    [main.cpp]
2021-03-10 ESP32 : Moving unused methods to private section
2021-03-11 ESP32 : Adding BLE LED blink when advertising
2021-03-11 ESP32 : Adding support for showing time & date
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2021-03-12 ESP32 : Fixing the WiFi connection failed bug
    [main.cpp]
2021-03-13 ESP32 : Updating the language node to match the new Azure profile
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2021-03-14 ESP32 : Fixing the precision issue with the average value
2021-03-14 ESP32 : Adding support for showing average values in OLED
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2021-03-14 ESP32 : forgot to evaluate the isWificonnected flag before fetching the time.
2021-03-15 ESP32 : Adding New Font size for displaying the Date without crop
2021-03-15 PCB : Adding HDC1080 in the design
    [KiCad-Design.dsn, KiCad-Design.kicad_pcb, KiCad-Design.sch]
2021-03-15 PCB : Adding the step file for HDC1080
2021-03-15 ESP32 : Making the external sensors TwoWire bus configurable
2021-03-15 ESP32 : Fixing the temperature subtraction error
2021-03-15 ESP32 : Support for multi-bus/interface OLED-Sensors * Fixing the local time reading error * Updating the measurement values in BLE characteristics
    [main.cpp]
2021-03-15 PCB : Using UMH3N package instead of PMBT3904
    [KiCad-Design.dsn, KiCad-Design.kicad_pcb, KiCad-Design.sch]
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2021-03-15 ESP32 : moving the general configuration in the separate header file
2021-03-17 PCB : detaching the sensors from the main PCB
    [KiCad-Design.sch]
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2021-03-17 PCB : Including the missing 3D step files
2021-03-17 PCB: Updating the PCB design file :)
    [KiCad-Design.dsn, KiCad-Design.kicad_pcb]
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2021-03-18 ESP32 : Adding Notifying Icons when Pushing Audio to Google Home Speaker
2021-03-19 ESP32 : Code improving
    * Fixing the bug with different I2C bus
    * improving the sensor type management
    * First attempt to use BSEC library
    * Fixing the measurements log print mistake
    [main.cpp]
2021-03-21 ESP32 : Fixing the sensor identification bug
    [config.h]
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2021-03-22 ESP32 : Fixing the Air Quality min/max/ave measurements
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2021-03-22 ESP32 : Adding Support for extended OLED display + BME680 calibration status
2021-03-22 ESP32 : Adding the missing definition
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2021-03-22 ESP32 : Printing the Gas resistance when BME680 is not calibrated
2021-03-22 ESP32 : Fixing the bug with the storing the average
2021-03-22 ESP32 : Auto restart when heap size is too-low (Azure IoT issues)
    [main.cpp]
2021-03-23 ESP32 : Accepting the Medium Accuracy for BME680
2021-03-23 ESP32 : Showing the L/M for Low and MEDIUM_ACCURACY
2021-03-24 ESP32 : Adding support for storing BSEC state in the Flash
2021-03-24 ESP32 : Adding full support for storing the BSEC lib state regularly
2021-03-24 ESP32 : Fixing the introduce bug
2021-03-24 ESP32 : Fixing the daily report reset (with this it will reset the report everyday at 6am or every 1440 minutes)
    [config.h, main.cpp]
2021-03-24 ESP32: resolving the local time using worldtimeapi.org api
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2021-03-25 ESP32 : Adding support for Air Quality Index in the BluetoothLE GATT
2021-03-25 ESP32 : Passing the Air Quality Index Value
2021-03-25 ESP32 : Fixing bug introduce by configuration thing
2021-03-25 ESP32 : Showing the Summary of Air Quality
2021-03-25 ESP32 : Fixing the bug with Flash memory address
2021-03-25 ESP32 : Adding ping feature for checking the connection
2021-03-25 ESP32 : Updating the UWP project to support the Air Quality and improve the visuals
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2021-03-27 ESP32 : Showing equivalent VOC in the display + improving the description for the AQI
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2021-03-28 ESP32: Fixing the missing verbose mode flag for sensor wrapper
    [main.cpp]
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2021-03-29 ESP32 : Fixing the VOC scale
2021-03-30 UWP: Updating the AOI in the sensor monitoring section + setting 19041 as target version
2021-04-02 MISC: Committing some left overs
    [KiCad-Design.kicad_pcb]
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2021-04-03 PCB: Moving the libraries to the project specific
    [KiCad-Design.sch]
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2021-04-06 ESP32: Disconnect WiFi if fails to ping the gateway + stop Azure if the internet is not available
    [main.cpp]
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2021-04-07 MCU: Introducing auto-reconnect. Known issue Azure Destroy
    [main.cpp]
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2021-04-08 ESP32: Adding the missing changes
2021-04-09 PCB: Updating TTGO library
    [KiCad-Design.sch]
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2021-04-11 PCB: Re-validating the Schematic design
    [KiCad-Design.sch]
2021-04-11 PCB: Updating the PCB design
    [KiCad-Design.dsn, KiCad-Design.kicad_pcb, KiCad-Design.sch]
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2021-04-12 PCB: Updating PCB layout
    [KiCad-Design.kicad_pcb]
2021-04-17 ESP32: Fixing the memory release + upgrading to latest espressif32 library
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
